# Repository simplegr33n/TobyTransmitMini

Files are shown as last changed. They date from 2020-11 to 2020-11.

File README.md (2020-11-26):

# Toby Transmit Mini

A battery powered Arduino Nano based 7+ channel RF controller.

## COMPONENTS

// Modules

- Arduino Nano microcontroller

- NRF24L01 RF module

- USB Charging circuit

- SSD1306 OLED screen

- 3-Color indicator LED

// Inputs

- On/Off switch

- XY+Switch Joystick

- Rotary Encoder with Momentary Switch

- Momentary Button

- Switch button

## Nano Pinout

| Pin | _module_ | _module pin_ | _notes_ |
| --- | --- | --- | --- |
| **_A0_** | Joystick | _X_ | X and Y may be swapped based on actual hardware config |
| **_A1_** | Joystick | _Y_ |
| **_A2_** | NRF24L01 | _CE_ |
| **_A3_** | NRF24L01 | _CSN_ |
| **_A4_** - _SDA_ | SSD1306 OLED | _SDA_ |
| **_A5_** - _SCL_ | SSD1306 OLED | _SCL_ |
| **_A6_** | | | \* Exclusively analog pin |
| **_A7_** | | | \* Exclusively analog pin |
| **_D0_** - _RX0_ | ---USB-COM--- | ---USB-COM--- | Transmitter needs to be able to connect with PC to update firmware, etc. therefore leave RX0 / TX1 free |
| **_D1_** - _TX1_ | ---USB-COM--- | ---USB-COM--- |
| **_D2_** | Joystick | _Sw_ |
| **_D3_** | Momentary Button | _Out_ |
| **_D4_** | Toggle Button | _Out_ |
| **_D5_** | Rotary Encoder | _CLK (Output A)_ |
| **_D6_** | Rotary Encoder | _DT (Output B)_  |
| **_D7_** | Rotary Encoder | _Sw_ |
| **_D8_** | 3-Color LED | _RED_ | 150 Ω |
| **_D9_** | 3-Color LED | _BLUE_ | 68 Ω |
| **_D10_** _SS_ | | |
| **_D11_** - _MOSI_ | NRF24L01 | _MOSI_ |
| **_D12_** - _MISO_ | NRF24L01 | _MISO_ |
| **_D13_** - _SCK_  | NRF24L01 | _SCK_ |

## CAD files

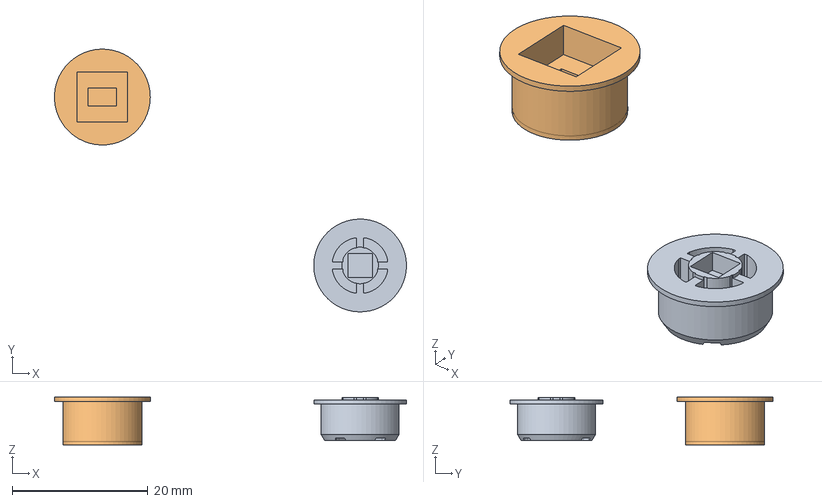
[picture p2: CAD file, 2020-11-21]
_3d/misc parts/button caps/v6/button caps v6.step
51.9 x 38.7 x 7.00 mm

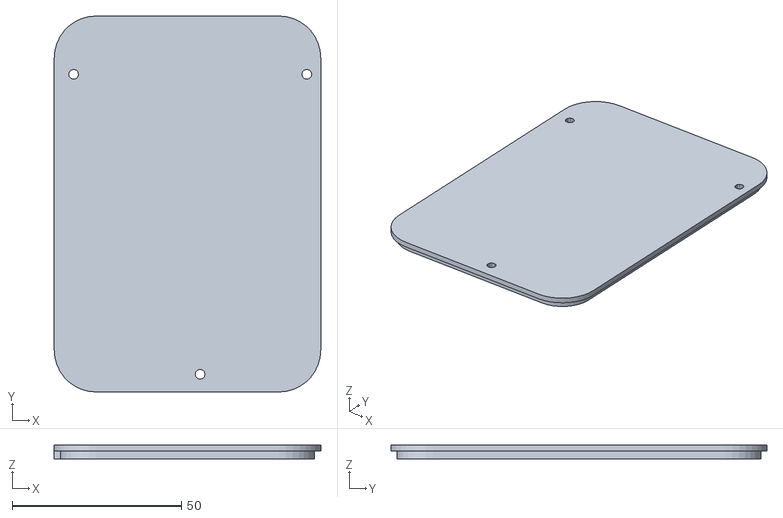
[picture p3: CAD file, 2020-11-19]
_3d/v2/BLANK/TobyTransmitterMini_BLANK_Back_v2.stl
78.7 x 111.0 x 4.10

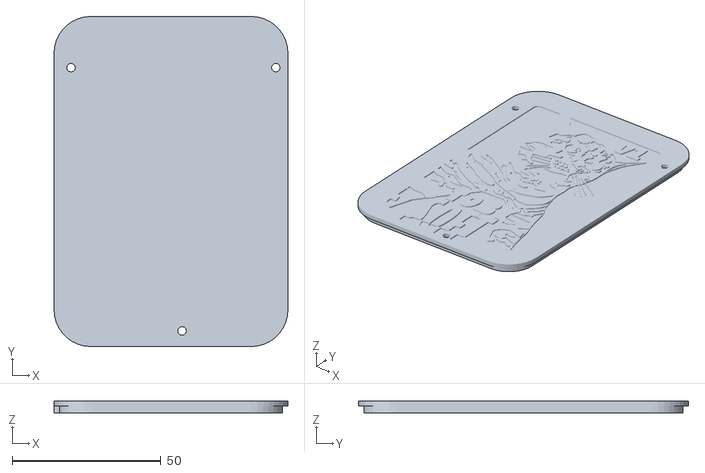
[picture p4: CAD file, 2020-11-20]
_3d/v2/DESIGN1/TobyTransmitterMini_Back_DESIGN1_v3.stl
78.7 x 111.0 x 4.10

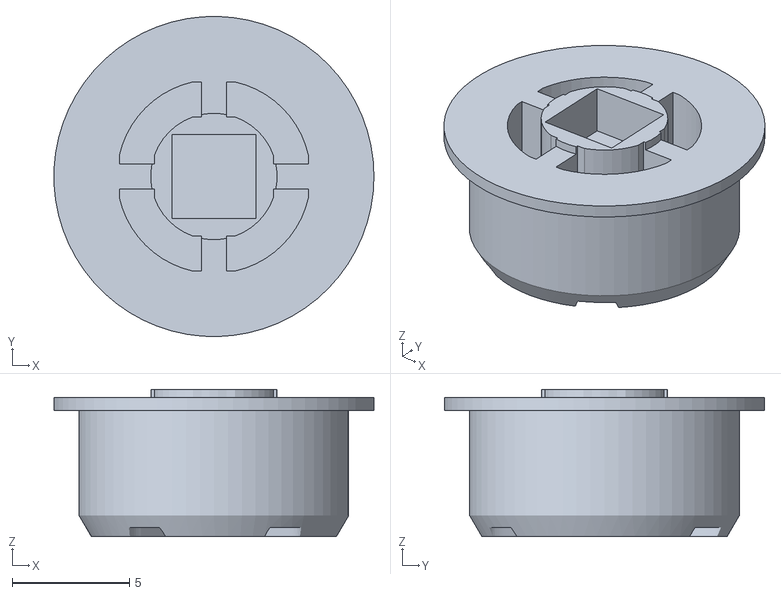
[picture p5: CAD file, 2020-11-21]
_3d/misc parts/button caps/v6/mnt_v6.stl
13.7 x 13.7 x 6.30

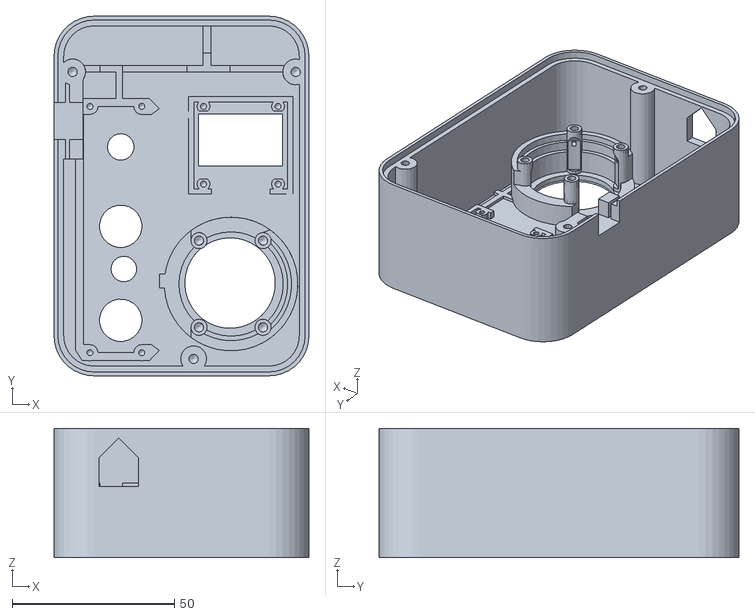
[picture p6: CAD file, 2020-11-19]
_3d/v2/BLANK/TobyTransmitterMini_BLANK_Body_v2.stl
78.7 x 111.0 x 39.9

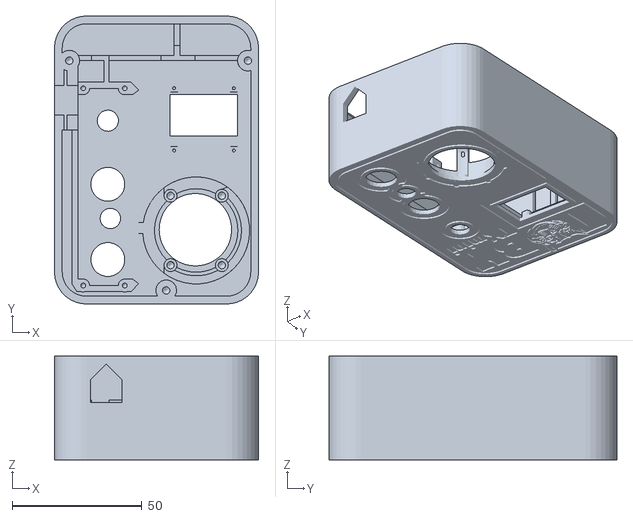
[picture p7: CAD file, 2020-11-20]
_3d/v2/DESIGN1/TobyTransmitterMini_Body_DESIGN1_v2.stl
78.7 x 111.0 x 39.9

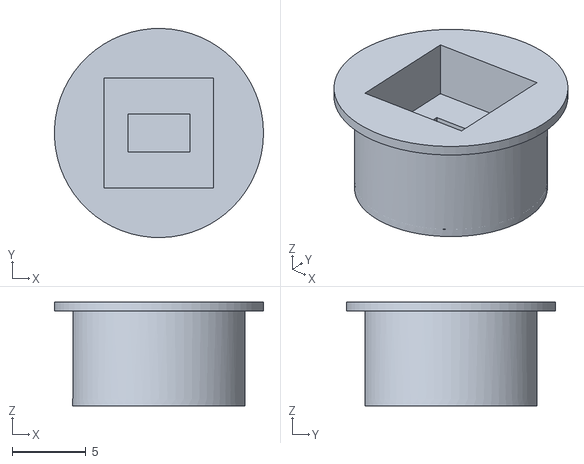
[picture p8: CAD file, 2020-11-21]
_3d/misc parts/button caps/v6/tgl_v6.stl
14.1 x 14.1 x 7.00

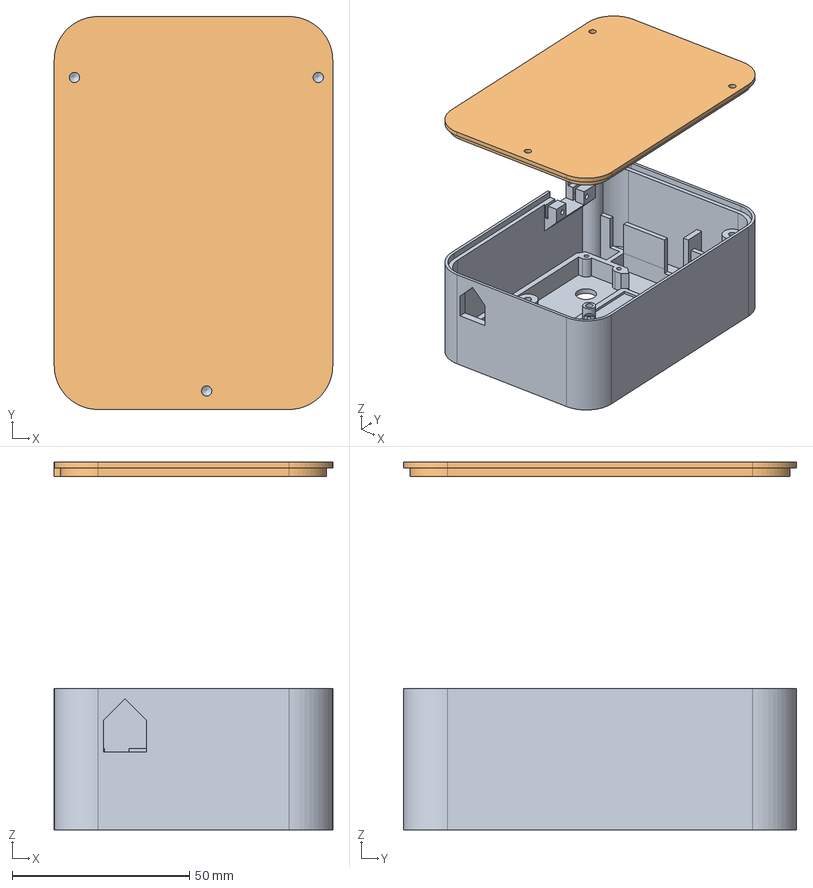
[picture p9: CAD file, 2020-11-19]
_3d/v2/BLANK/TobyTransmitterMini_BLANK_v2.step
78.7 x 111.0 x 103.8 mm

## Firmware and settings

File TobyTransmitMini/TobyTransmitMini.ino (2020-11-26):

bool TxOsRunning = false; // TODO: does nothing for now, but could be used to reboot OS in cases of lost NRF cxn, etc.

/////////////////////////////////////////////////////////////////////////////////////////////////////////
// Hardware Inputs                                                                                     //
/////////////////////////////////////////////////////////////////////////////////////////////////////////
int joystick0ValueX;
int joystick0ValueY;
int joystick0ValueSw;

int bigRedButtonValue;
int bigYellowButtonValue;

int encoderSwitchValue;
volatile int encoderCounter = 0;

/////////////////////////////////////////////////////////////////////////////////////////////////////////
// OS vars                                                                                             //
/////////////////////////////////////////////////////////////////////////////////////////////////////////
int MENU_STATE = 0; // 0 = off, 1 = Main Menu, 2 = Vehicle Settings, 3 = Controller Settings, 4 = Datalog
volatile int MenuPosition;
int SETTING_STATE = 0; // 0 = off, 1 = Active
volatile int SettingPosition;

/////////////////////////////////////////////////////////////////////////////////////////////////////////
// Controller Settings (Menu)                                                                          //
/////////////////////////////////////////////////////////////////////////////////////////////////////////
int settingLEDBrightness = 10; // 0 - 10

/////////////////////////////////////////////////////////////////////////////////////////////////////////
// Vehicle Settings (Menu)                                                                             //
/////////////////////////////////////////////////////////////////////////////////////////////////////////

/////////////////////////////////////////////////////////////////////////////////////////////////////////
// Datalog (Menu)                                                                                      //
/////////////////////////////////////////////////////////////////////////////////////////////////////////

/////////////////////////////////////////////////////////////////////////////////////////////////////////
// ///////////////                                                                                     //
// END GLOBAL VARS                                                                                     //
// ///////////////                                                                                     //
/////////////////////////////////////////////////////////////////////////////////////////////////////////

void setup()
{
    bootTxOs();
}

void loop()
{
    if (TxOsRunning)
    {
        TxOsLoop();
    }
    else
    {
        bootTxOs();
    }
}

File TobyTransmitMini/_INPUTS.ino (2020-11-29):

#define JOYSTICK0_X_Pin A0
#define JOYSTICK0_Y_Pin A1
#define JOYSTICK0_SW_Pin 2

#define BIG_RED_BUTTON_Pin 3
#define BIG_YELLOW_BUTTON_Pin 4

#define ENCODER_CLK_Pin 5
#define ENCODER_DT_Pin 6
#define ENCODER_SW_Pin 7

volatile uint8_t ENCODER_PHASE;
volatile uint8_t PREV_ENCODER_PHASE;
volatile bool ENCODER_INCREASE;
volatile bool ENCODER_DECREASE;

/////////////////////////////////////////////////////////////////////////////////////////////////////////
// ///////////////                                                                                     //
// END GLOBAL VARS                                                                                     //
// ///////////////                                                                                     //
/////////////////////////////////////////////////////////////////////////////////////////////////////////

void initInputs()
{
    // Set up pin for joystick switch function
    pinMode(JOYSTICK0_SW_Pin, INPUT);
    digitalWrite(JOYSTICK0_SW_Pin, HIGH);

    // Set up button pins
    pinMode(BIG_RED_BUTTON_Pin, INPUT);
    pinMode(BIG_YELLOW_BUTTON_Pin, INPUT);

    // Set up encoder pots and switch
    pinMode(ENCODER_CLK_Pin, INPUT);
    pinMode(ENCODER_DT_Pin, INPUT);
    pinMode(ENCODER_SW_Pin, INPUT);

    // Initialize Encoder interrupts
    cli();
    ENCODER_PHASE = PIND;                      // Get state of Port D
    PCICR |= (1 << PCIE2);                     // Pin Change Interrupt Control Register enabling Port K
    PCMSK2 |= (1 << PCINT21) | (1 << PCINT22); // Enable mask on PCINT21-22 to trigger interrupt on state change
    sei();
}

/////////////////////////////////////////////////////////////////////////////////////////////////////////
// Input functions                                                                                     //
/////////////////////////////////////////////////////////////////////////////////////////////////////////
// Handle Pin Change Interrupt Vector
ISR(PCINT2_vect)
{
    cli();
    PREV_ENCODER_PHASE = ENCODER_PHASE;
    ENCODER_PHASE = PIND; // Get state of Port D

    if ((ENCODER_PHASE != PREV_ENCODER_PHASE))
    {
        if (ENCODER_PHASE & 0b01000000 && !(PREV_ENCODER_PHASE & 0b01000000)) // if CLK pin has changed
        {
            if (ENCODER_PHASE & 0b00100000) // if CLK differs from DT
            {
                updateEncoderCounters(-1); // decrease
                return;
            }
            else
            {
                updateEncoderCounters(1); // increase
                return;
            }
        }

        //  NOTE: Only using CLK changes to both keep ISR short and because higher acuity makes the cursor move to quickly in the menu
        // setable rotary sensitivity may be a nice feature, but might best be accomplished here with a simple multiplier
    }
    sei();
}

void updateEncoderCounters(int changeValue)
{
    if (SETTING_STATE != 0) // if currently setting
    {
        SettingPosition += changeValue;
        return;
    }
    else if (MENU_STATE != 0) // if currently in menu
    {
        MenuPosition += changeValue;
        return;
    }
    else
    {
        encoderCounter += changeValue; // only change actual encoder counter (a value which is transmitted) if not in menu/setting something
    }
}

void updateInputs()
{
    getJoystick0Values();
    getButtonValues();
}

void getJoystick0Values() // Joystick X value
{
    int xPotValue = analogRead(JOYSTICK0_X_Pin);
    joystick0ValueX = map(xPotValue, 0, 1023, 0, 180); // Joystick X value
    int yPotValue = analogRead(JOYSTICK0_Y_Pin);
    joystick0ValueY = map(yPotValue, 0, 1023, 0, 180); // Joystick Y value
}

void getButtonValues()
{
    bigRedButtonValue = digitalRead(BIG_RED_BUTTON_Pin);       // Big red button value
    bigYellowButtonValue = digitalRead(BIG_YELLOW_BUTTON_Pin); // Big yellow button value

    joystick0ValueSw = 0; // Joystick Switch value
    if (digitalRead(JOYSTICK0_SW_Pin) == 0)
    {
        joystick0ValueSw = 1;
    }

    encoderSwitchValue = 0; // Encoder switch value
    if (digitalRead(ENCODER_SW_Pin) == 0)
    {
        encoderSwitchValue = 1;
    }
}

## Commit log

2020-11-18 wrote up potential wiring
2020-11-19 revised transmitter case
    [TobyTransmitterMini_BLANK_Back_v1.stl, TobyTransmitterMini_BLANK_Back_v1r.stl, TobyTransmitterMini_BLANK_Body_v1.stl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]
2020-11-19 more revisions
    [TobyTransmitterMini_BLANK_Body_v1r.stl, TobyTransmitterMini_BLANK_Body_v1r2.stl, TobyTransmitterMini_BLANK_v1r.step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]
2020-11-19 revised code slightly for nano
    [TobyTransmitterMini_BLANK_Back_v1r.stl, TobyTransmitterMini_BLANK_Back_v1r2.stl, TobyTransmitterMini_BLANK_Back_v2.stl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]
2020-11-20 added rotary encoder and 2 leds. only 3 open pins on the duino!
2020-11-20 updated back design
    [TobyTransmitterMini_Back_DESIGN1_v3.stl, TobyTransmitterMini_Body_DESIGN1_v2.stl]
2020-11-20 improved rotary encoder reading
2020-11-20 designed some buttons to test
    [01momentary(BLK).stl, 01switch(BLU).stl, 02momentary(BLK).stl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]
2020-11-20 added a couple more buttons
    [01momentary(BLK).stl, 01switch(BLU).stl, 02momentary(BLK).stl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]
2020-11-20 new longer switch buttons
    [01switch(BLU).stl, 02switch(BLU).stl, 03switch(BLU).stl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]
2020-11-20 fixed files
    [04switch(BLU).stl, button caps v2.step]
2020-11-20 added reduced diameter buttons. hopefully good fit
    [01momentary(BLK).stl, 02momentary(BLK).stl, 03momentary(BLK).stl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]
2020-11-20 new switches
    [01switch(BLU).stl, 02switch(BLU).stl, 03switch(BLU).stl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]
2020-11-20 deleted old buttons
    [01momentary(BLK).stl, 01switch(BLU).stl, 02momentary(BLK).stl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]
2020-11-26 improved encoder reading
2020-11-26 first menu option item working ... (buggily :P)
    [_INPUTS.ino, _OLED.ino, _TX_OS.ino]
2020-11-26 improved mapping for LED PWM values
2020-11-29 calling the encoder licked for now
